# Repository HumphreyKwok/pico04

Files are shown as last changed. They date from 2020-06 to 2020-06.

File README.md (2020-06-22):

# pico04
A Cherry MX 4-key pad for fun. </br>
Cosidering the size limitation, Atemage16u2MU is used instead of 32u4AU. </br>
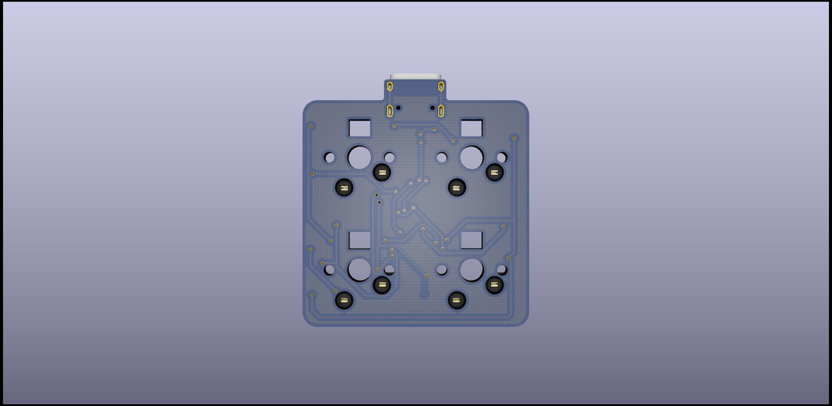
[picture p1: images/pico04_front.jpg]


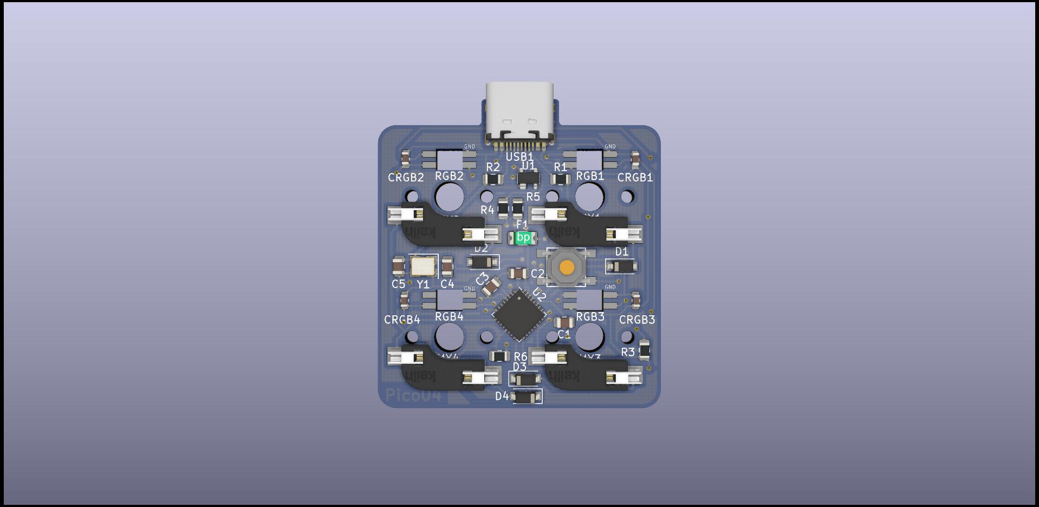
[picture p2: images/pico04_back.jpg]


## Features
- USB Type-C connector
- ESD protection
- Support per-switch RGB backlight
- Hotswappable
- Support QMK firmware

## Upcoming featues
- Bottom mount PCB case
- Support VIA

## Acknowledgements
Basically I designed this board on ai03's tutorial, step by step. This PCB won't even exist without the help of ai03's previous works and foorprint libraies.
On the other hand, coseyfannitutti and Hadi Iskandarani also advise me a lot during the development of this project. </br>

ai03's wiki and PCB : https://wiki.ai03.me/books/pcb-design </br>

coseyfannitutti's github : https://github.com/coseyfannitutti </br>

Hadi's Youtube Channel and machanical keyboard design tutorials : https://youtu.be/BhFqkVggv8Q </br>

Thanks all.

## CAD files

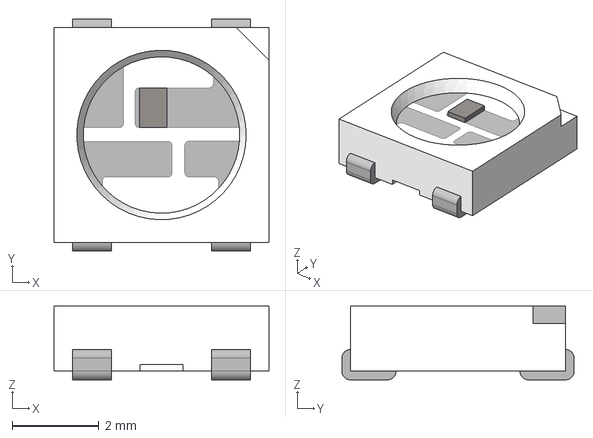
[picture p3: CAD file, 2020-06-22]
3d models/WS2812_RGB_LED.stp
4.95 x 5.35 x 1.70 mm

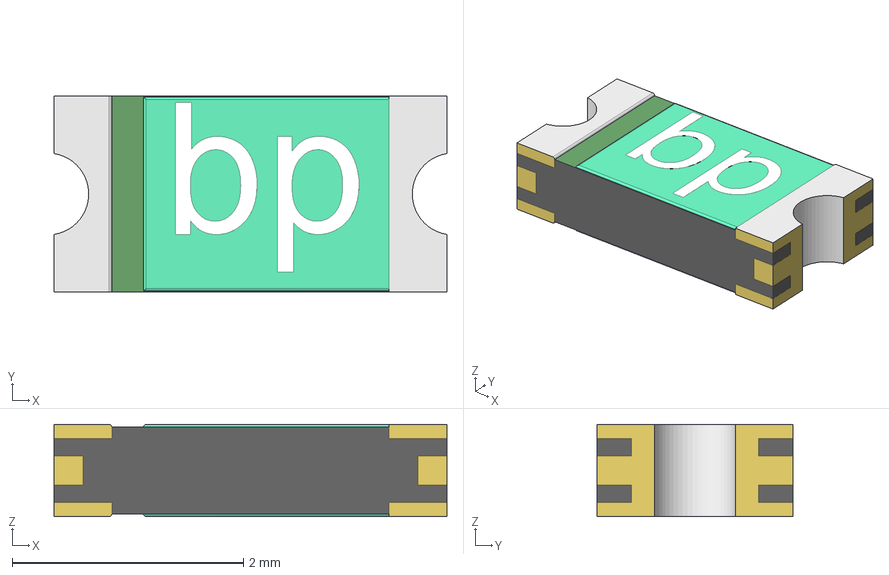
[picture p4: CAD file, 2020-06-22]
3d models/0ZCJ0050AF2E.step
3.40 x 1.70 x 0.8 mm

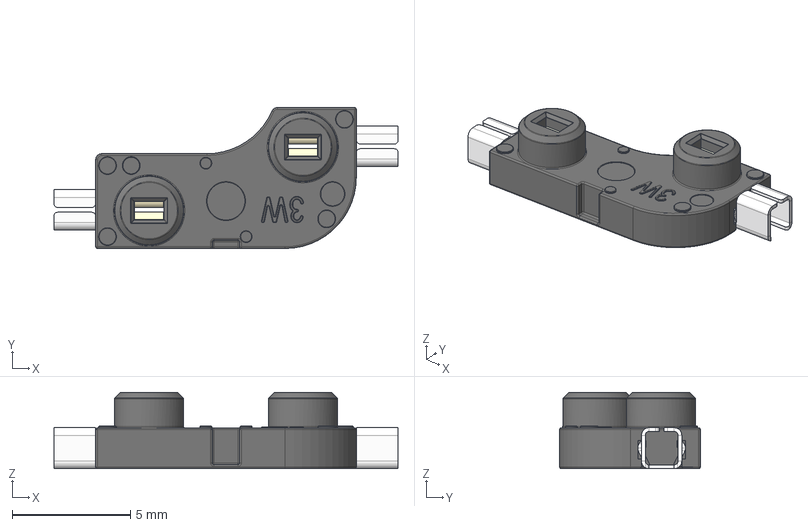
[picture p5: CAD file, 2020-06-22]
3d models/Kailh Hotswap MX v22.step
14.5 x 5.95 x 3.22 mm

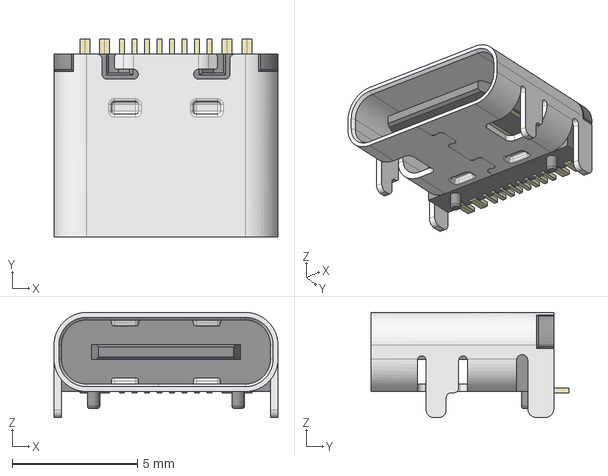
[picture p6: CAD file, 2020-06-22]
3d models/HRO_TYPE-C-31-M-12.step
8.95 x 7.90 x 4.20 mm

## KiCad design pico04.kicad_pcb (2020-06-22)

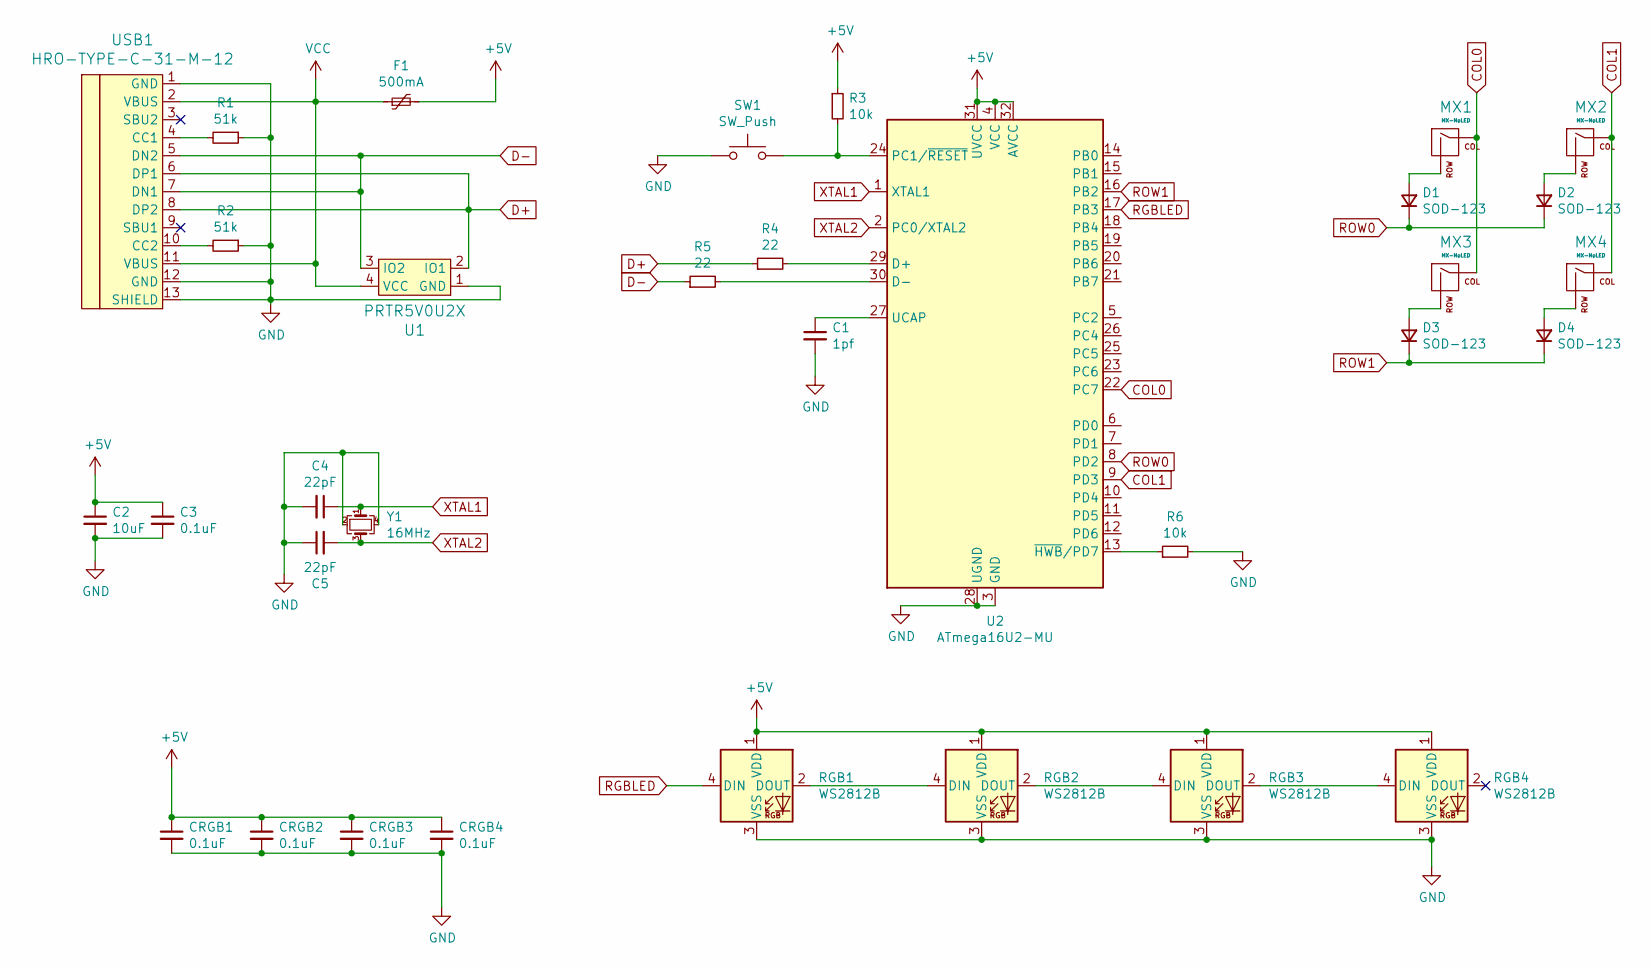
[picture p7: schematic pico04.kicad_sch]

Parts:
C1: 1pf; C_0805_2012Metric
C2: 10uF; C_0805_2012Metric
C3: 0.1uF; C_0805_2012Metric
C4, C5: 22pF; C_0805_2012Metric
CRGB1, CRGB2, CRGB3, CRGB4: 0.1uF; C_0603_1608Metric
D1, D2, D3, D4: SOD-123; D_SOD-123
F1: 500mA; Fuse_1206_3216Metric
MX1, MX2, MX3, MX4: MX-NoLED; MXOnly-1U-Hotswap
R1, R2: 51k; R_0805_2012Metric
R3, R6: 10k; R_0805_2012Metric
R4, R5: 22; R_0805_2012Metric
RGB1, RGB2, RGB3, RGB4: WS2812B; WS2812B-3528
SW1: SW_Push; SKQGADE010
U1: PRTR5V0U2X; SOT143B
U2: ATmega16U2-MU; QFN-32-1EP_5x5mm_P0.5mm_EP3.1x3.1mm
USB1: HRO-TYPE-C-31-M-12
Y1: 16MHz; Crystal_SMD_3225-4Pin_3.2x2.5mm

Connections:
+5V: C2.1, C3.1, CRGB1.1, CRGB2.1, CRGB3.1, CRGB4.1, F1.2, R3.1, RGB1.1 (VDD), RGB2.1 (VDD), RGB3.1 (VDD), RGB4.1 (VDD), U2.4 (VCC), U2.31 (UVCC), U2.32 (AVCC)
COL0: MX1.1 (COL), MX3.1 (COL), U2.22 (PC7)
COL1: MX2.1 (COL), MX4.1 (COL), U2.9 (PD3)
D+: R4.1, U1.2 (IO1), USB1.6 (DP1), USB1.8 (DP2)
D-: R5.1, U1.3 (IO2), USB1.5 (DN2), USB1.7 (DN1)
GND: C1.2, C2.2, C3.2, C4.2, C5.1, CRGB1.2, CRGB2.2, CRGB3.2, CRGB4.2, R1.1, R2.1, R6.2, RGB1.3 (VSS), RGB2.3 (VSS), RGB3.3 (VSS), RGB4.3 (VSS), SW1.1, U1.1 (GND), U2.3 (GND), U2.28 (UGND), U2.33 (GND), USB1.1 (GND), USB1.12 (GND), USB1.13 (SHIELD), Y1.2, Y1.4
unnamed: C1.1, U2.27 (UCAP)
unnamed: D1.2 (A), MX1.2 (ROW)
unnamed: D2.2 (A), MX2.2 (ROW)
unnamed: D3.2 (A), MX3.2 (ROW)
unnamed: D4.2 (A), MX4.2 (ROW)
unnamed: R1.2, USB1.4 (CC1)
unnamed: R2.2, USB1.10 (CC2)
unnamed: R3.2, SW1.2, U2.24 (PC1/~RESET)
unnamed: R4.2, U2.29 (D+)
unnamed: R5.2, U2.30 (D-)
unnamed: R6.1, U2.13 (~HWB~/PD7)
unnamed: RGB1.2 (DOUT), RGB2.4 (DIN)
unnamed: RGB2.2 (DOUT), RGB3.4 (DIN)
unnamed: RGB3.2 (DOUT), RGB4.4 (DIN)
RGBLED: RGB1.4 (DIN), U2.17 (PB3)
ROW0: D1.1 (K), D2.1 (K), U2.8 (PD2)
ROW1: D3.1 (K), D4.1 (K), U2.16 (PB2)
VCC: F1.1, U1.4 (VCC), USB1.2 (VBUS), USB1.11 (VBUS)
XTAL1: C4.1, U2.1 (XTAL1), Y1.1
XTAL2: C5.2, U2.2 (PC0/XTAL2), Y1.3

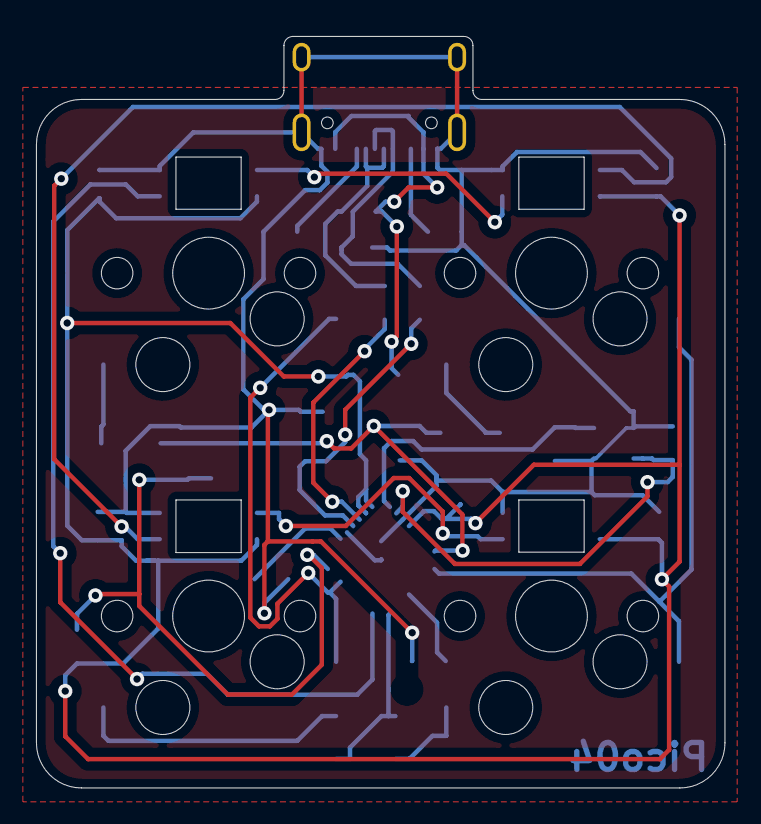
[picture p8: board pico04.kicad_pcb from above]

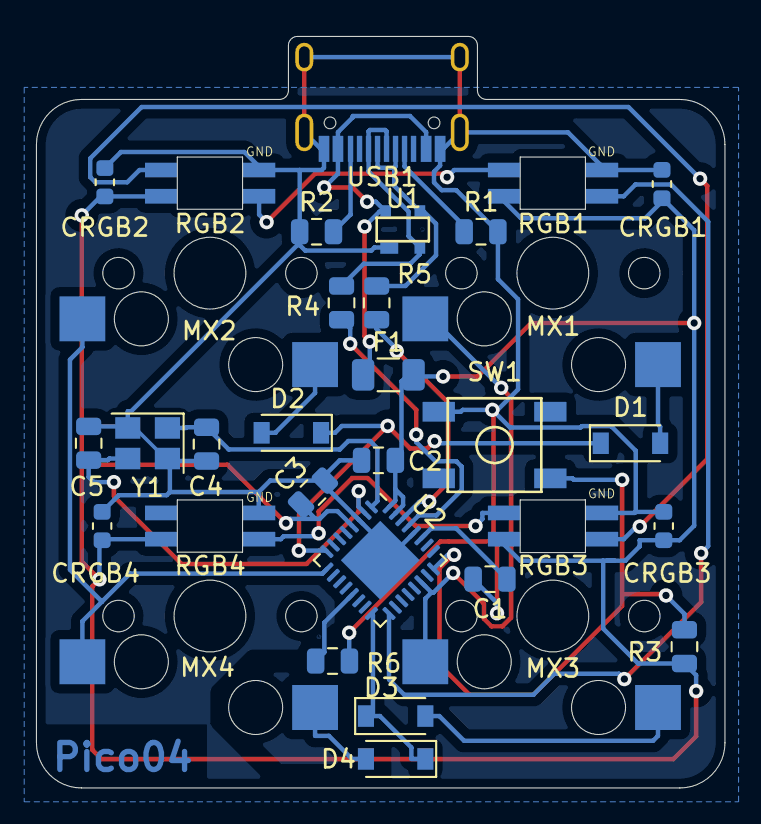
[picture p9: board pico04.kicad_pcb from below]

Board: 2 copper layers, 38.2 x 41.8 mm, 33 parts (29 on the bottom side), 26 nets.

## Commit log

2020-06-21 Add footprint libraries
2020-06-21 Complete the schematic
    [pico04.kicad_pcb, pico04.kicad_sch]
2020-06-21 Created a ws2812-3528 footprint
2020-06-21 Place the footprint on the PCB
    [pico04.kicad_pcb, pico04.kicad_sch]
2020-06-22 Complete the PCB
    [pico04.kicad_pcb, pico04.kicad_sch]
2020-06-22 Add some 3d models to the PCB
    [0ZCJ0050AF2E.step, HRO_TYPE-C-31-M-12.step, Kailh Hotswap MX v22.step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]
2020-06-22 Fix 3d model issues
    [WS2812_RGB_LED.stp, pico04.kicad_pcb]
2020-06-22 Add 3d images of the PCB
2020-06-22 Re-route the PCB
2020-06-22 Optimize some routing and update the images
    [pico04.kicad_pcb]

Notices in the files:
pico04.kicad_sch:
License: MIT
